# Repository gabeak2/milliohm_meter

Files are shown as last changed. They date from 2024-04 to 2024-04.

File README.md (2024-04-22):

# milliohm_meter
A milliohm meter PCBA reading 10V/Ohm, designed to be powered off of a RCR123A battery.  It plugs directly into standard DVMs with 2 male banana pins with 19mm spacing, and uses kelvin sensing for resistance readings.  


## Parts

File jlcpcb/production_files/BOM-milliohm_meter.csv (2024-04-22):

Comment | Designator | Footprint | LCSC
1k | R13 | C_0402_1005Metric | C11702
OPA388 | U2 | SOIC-8_3.9x4.9mm_P1.27mm | C154118
0 | R3,R8 | R_0402_1005Metric | C17168
D_Schottky | D1 | D_SOD-323 | C191023
INA333xxDGK | U3 | VSSOP-8_3.0x3.0mm_P0.65mm | C19450
AO3400A | Q1,Q2 | SOT-23 | C20917
JS102011SAQN | SW1 | SW_SPDT_CK_JS102011SAQN | C221660
10 | R10,R9 | C_0402_1005Metric | C25077
220 | R7 | C_0402_1005Metric | C25091
100nF | C1,C2 | C_0402_1005Metric | C307331
CJ431 | U1 | SOT-23 | C3113
47k | R11,R12,R15,R5,R6 | C_0402_1005Metric | C358418
100 | R1,R2,R4 | C_0402_1005Metric | C705656
LED_RED | D2 | LED_0805_2012Metric | C84256
72918 | J8 | MountingHole_3.2mm_M3_Pad
Conn_01x01 | J2 | CT3149
Conn_01x02 | J3 | PinSocket_1x02_P2.54mm_Vertical
DNS | C3 | C_0402_1005Metric
Conn_01x01 | J6 | CT3149
Conn_01x02 | J4 | PinSocket_1x02_P2.54mm_Vertical
72918 | J7 | MountingHole_3.2mm_M3_Pad
Conn_01x01 | J5 | CT3149
Conn_01x01 | J1 | CT3149
BH123A | BAT1 | BH123A

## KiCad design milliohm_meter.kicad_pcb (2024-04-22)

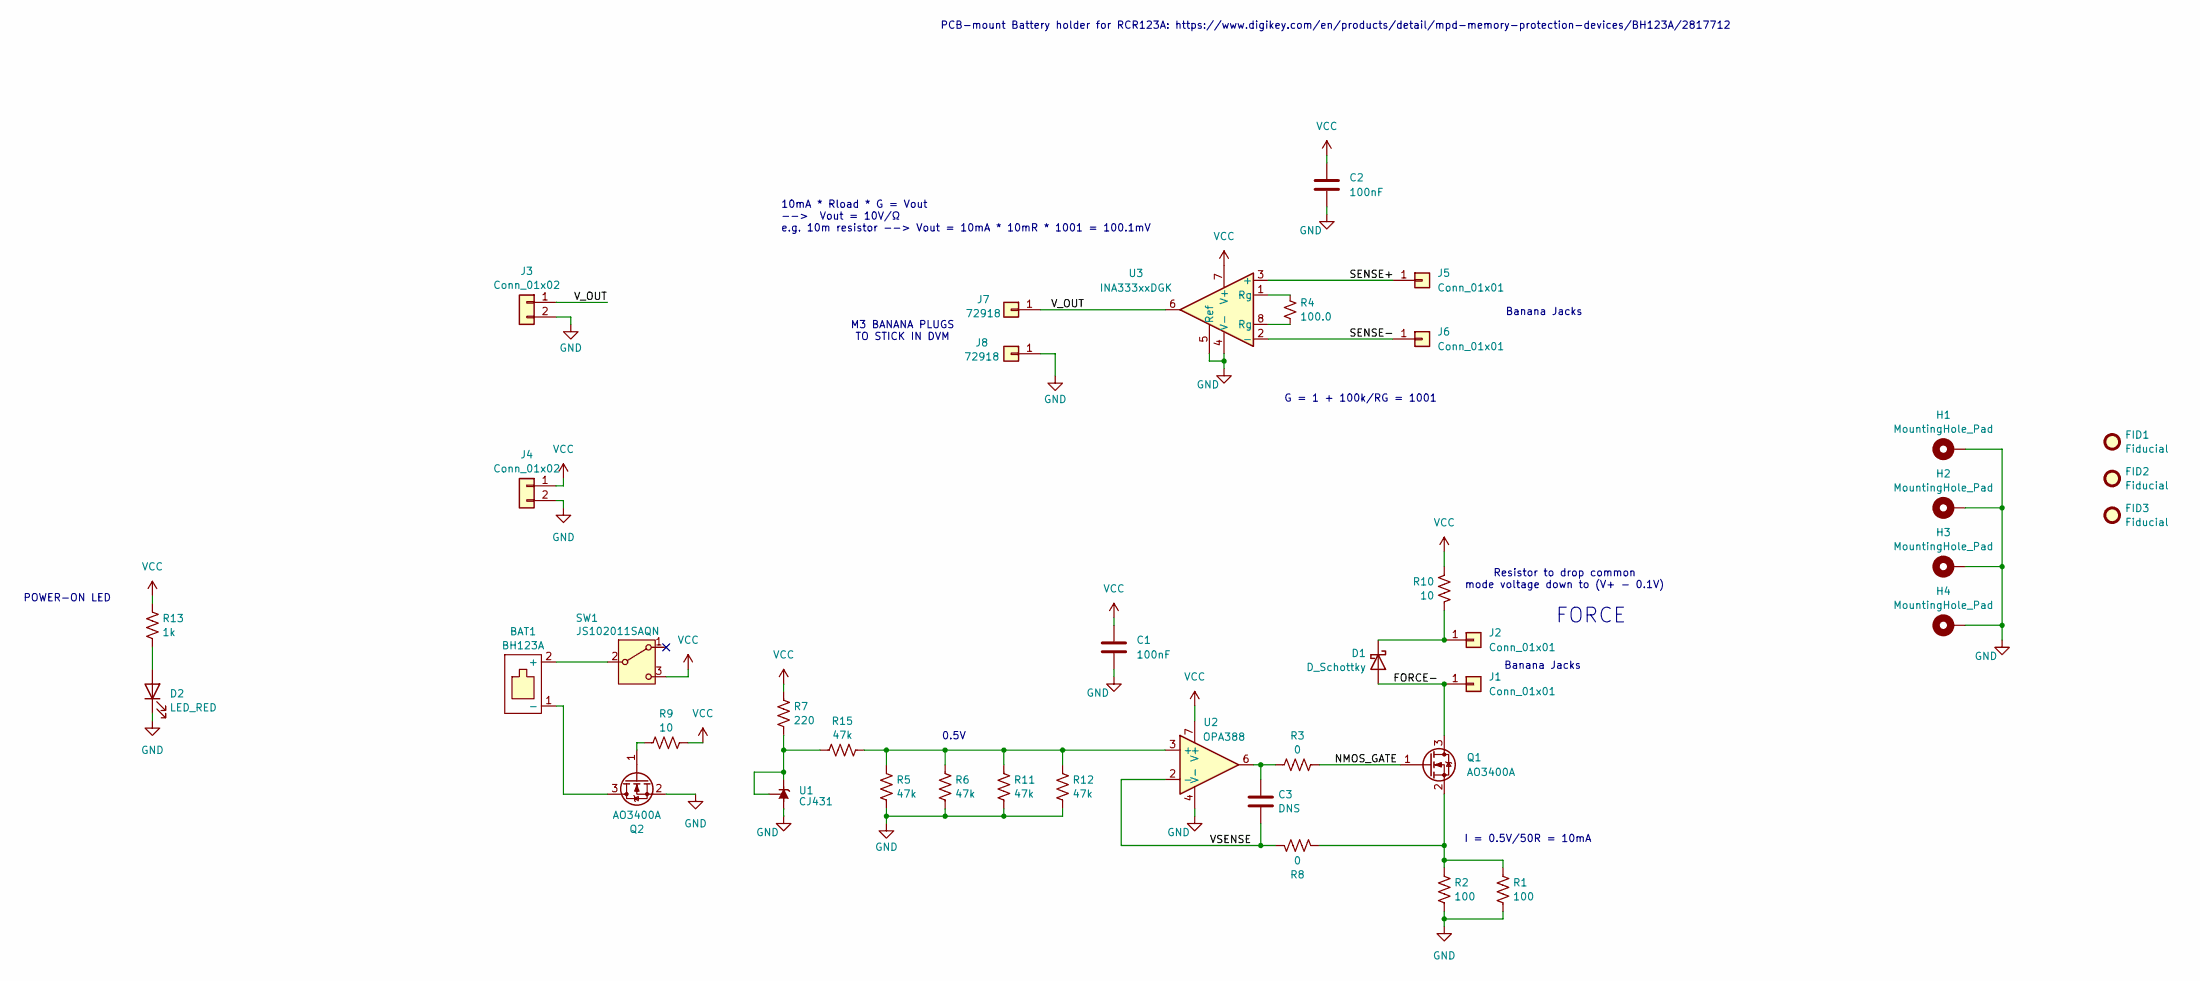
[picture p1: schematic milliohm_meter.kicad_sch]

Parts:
BAT1: BH123A
C1, C2: 100nF; C_0402_1005Metric; LCSC C307331
C3: DNS; C_0402_1005Metric
D1: D_Schottky; D_SOD-323; LCSC C191023
D2: LED_RED; LED_0805_2012Metric; LCSC C84256
FID1, FID2, FID3: Fiducial; Fiducial_1mm_Mask2mm
H1, H2, H3, H4: MountingHole_Pad; MountingHole_3.2mm_M3_Pad
J1, J2, J5, J6: Conn_01x01; CT3149
J3, J4: Conn_01x02; PinSocket_1x02_P2.54mm_Vertical
J7, J8: 72918; MountingHole_3.2mm_M3_Pad
Q1, Q2: AO3400A; SOT-23; LCSC C20917
R1, R2: 100; C_0402_1005Metric; LCSC C705656
R3, R8: 0; R_0402_1005Metric; LCSC C17168
R4: 100.0; C_0402_1005Metric; LCSC C705656
R5, R6, R11, R12, R15: 47k; C_0402_1005Metric; LCSC C358418
R7: 220; C_0402_1005Metric; LCSC C25091
R9, R10: 10; C_0402_1005Metric; LCSC C25077
R13: 1k; C_0402_1005Metric; LCSC C11702
SW1: JS102011SAQN; SW_SPDT_CK_JS102011SAQN; LCSC C221660
U1: CJ431; SOT-23; LCSC C3113
U2: OPA388; SOIC-8_3.9x4.9mm_P1.27mm; LCSC C154118
U3: INA333xxDGK; VSSOP-8_3.0x3.0mm_P0.65mm; LCSC C19450

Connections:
/FORCE-: D1.2 (A), J1.1, Q1.3 (D)
/NMOS_GATE: Q1.1 (G), R3.1
/SENSE+: J5.1, U3.3 (+)
/SENSE-: J6.1, U3.2 (-)
/VSENSE: C3.2, R8.2, U2.2 (-)
/V_OUT: J3.1, J7.1, U3.6
GND: C1.2, C2.2, D2.1 (K), H1.1, H2.1, H3.1, H4.1, J3.2, J4.2, J8.1, Q2.2 (S), R1.2, R2.2, R5.1, R6.1, R11.1, R12.1, U1.3 (A), U2.4 (V-), U3.4 (V-), U3.5 (Ref)
unnamed: BAT1.2 (+), SW1.2 (B)
unnamed: BAT1.1 (-), Q2.3 (D)
unnamed: C3.1, R3.2, U2.6
unnamed: D1.1 (K), J2.1, R10.2
unnamed: D2.2 (A), R13.1
unnamed: Q1.2 (S), R1.1, R2.1, R8.1
unnamed: Q2.1 (G), R9.1
unnamed: R4.1, U3.1 (Rg)
unnamed: R4.2, U3.8 (Rg)
unnamed: R7.2, R15.1, U1.1 (REF), U1.2 (K)
unnamed: R5.2, R6.2, R11.2, R12.2, R15.2, U2.3 (+)
VCC: C1.1, C2.1, J4.1, R7.1, R9.2, R10.1, R13.2, SW1.3 (C), U2.7 (V+), U3.7 (V+)

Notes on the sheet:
Resistor to drop common mode voltage down to (V+ - 0.1V)
POWER-ON LED
0.5V
M3 BANANA PLUGS TO STICK IN DVM
I = 0.5V/50R = 10mA
FORCE
10mA * Rload * G = Vout --> Vout = 10V/Ω e.g. 10m resistor --> Vout = 10mA * 10mR * 1001 = 100.1mV
Banana Jacks
G = 1 + 100k/RG = 1001
PCB-mount Battery holder for RCR123A: https://www.digikey.com/en/products/detail/mpd-memory-protection-devices/BH123A/2817712

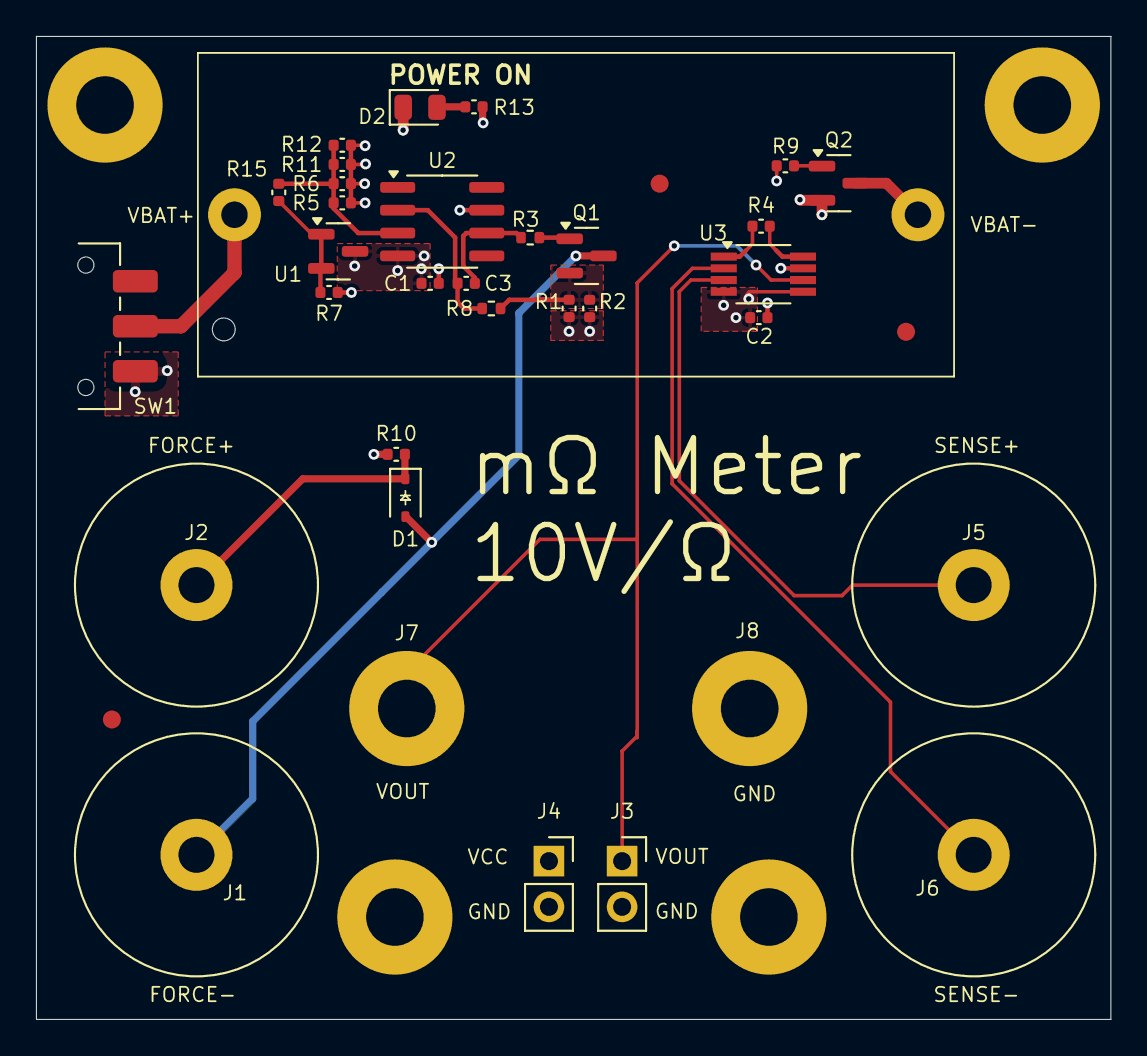
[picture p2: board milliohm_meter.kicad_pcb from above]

Board: 4 copper layers, 59.7 x 54.6 mm, 41 parts (1 on the bottom side), 19 nets.
